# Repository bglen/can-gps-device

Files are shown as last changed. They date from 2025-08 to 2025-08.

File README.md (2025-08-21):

# can-gps-device

| Side | Top |
| --- | --- |
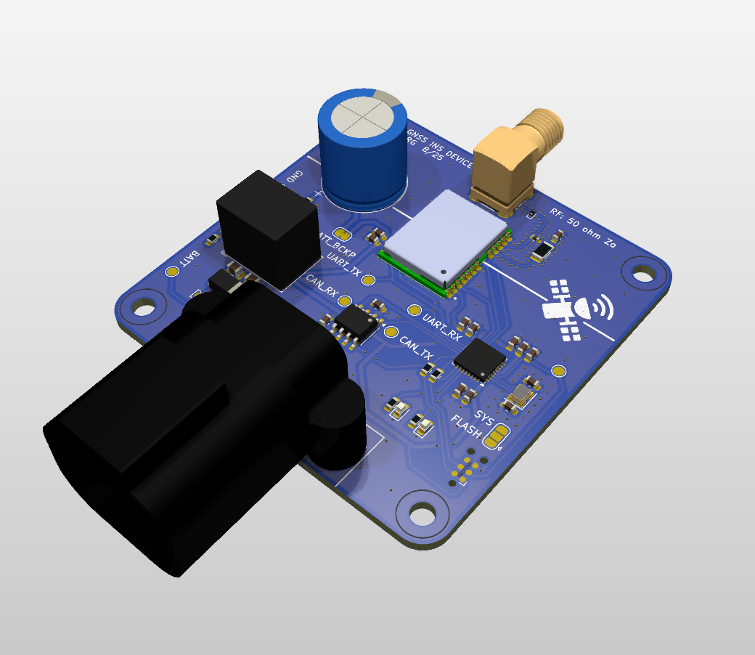
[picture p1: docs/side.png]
side
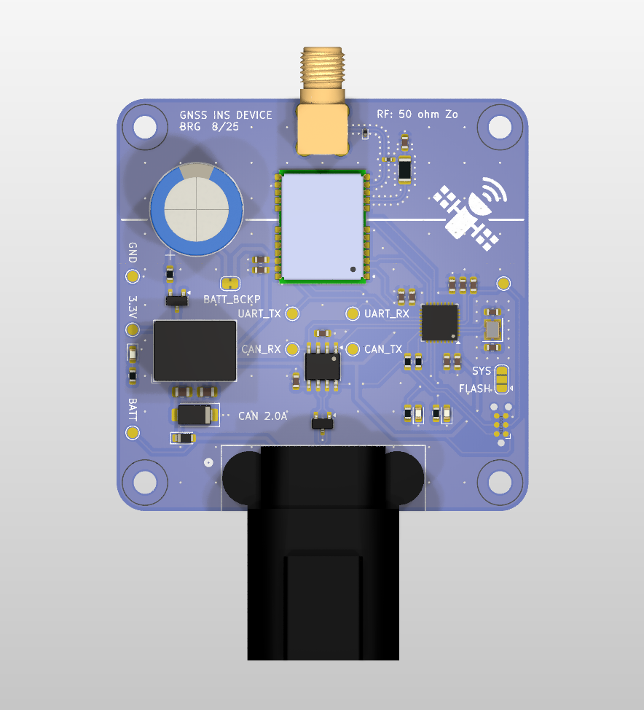
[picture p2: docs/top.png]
|  |  |

Simple, easy to use GPS module for CAN bus-networked vehicles.
- ublox NEO-M90V-20B GNSS + IMU dead reckoning module
- STM32F042
- CAN 2.0B
- Super capacitor circuit supports hot-start up to 30 minutes after first lock
- ublox ANN-MB5 antenna recomended

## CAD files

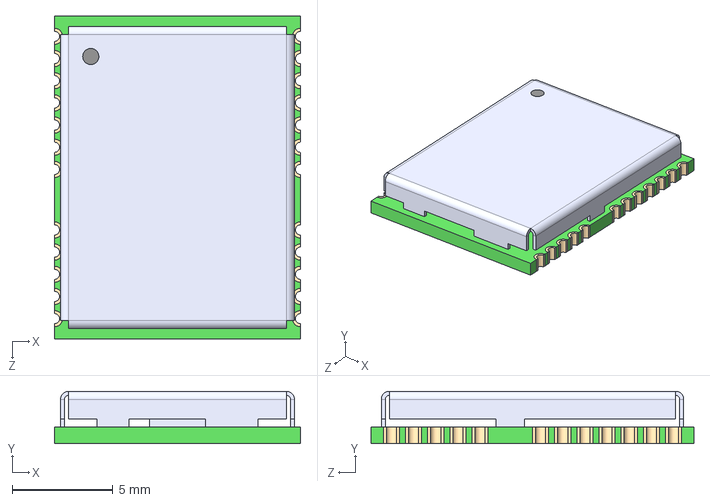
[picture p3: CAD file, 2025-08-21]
hardware/can_gps_device/3d_models/NEO-M9V-20B.step
12.2 x 2.60 x 16.0 mm

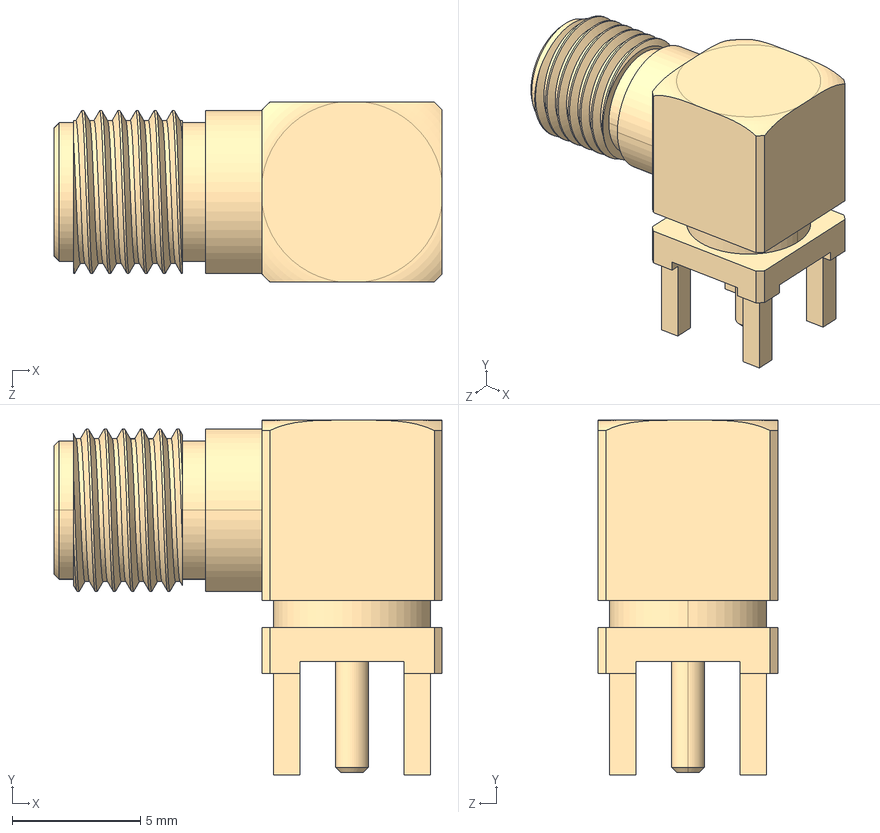
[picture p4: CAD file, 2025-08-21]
hardware/can_gps_device/3d_models/SMA-J-P-H-RA-TH1.STEP
15.1 x 13.8 x 7.00 mm

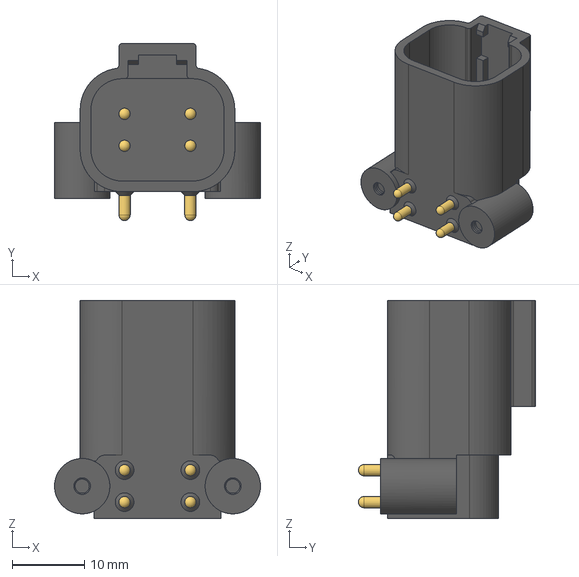
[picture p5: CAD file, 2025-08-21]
hardware/can_gps_device/3d_models/ATF13-4P-BM11.stp
28.5 x 24.5 x 30.2 mm

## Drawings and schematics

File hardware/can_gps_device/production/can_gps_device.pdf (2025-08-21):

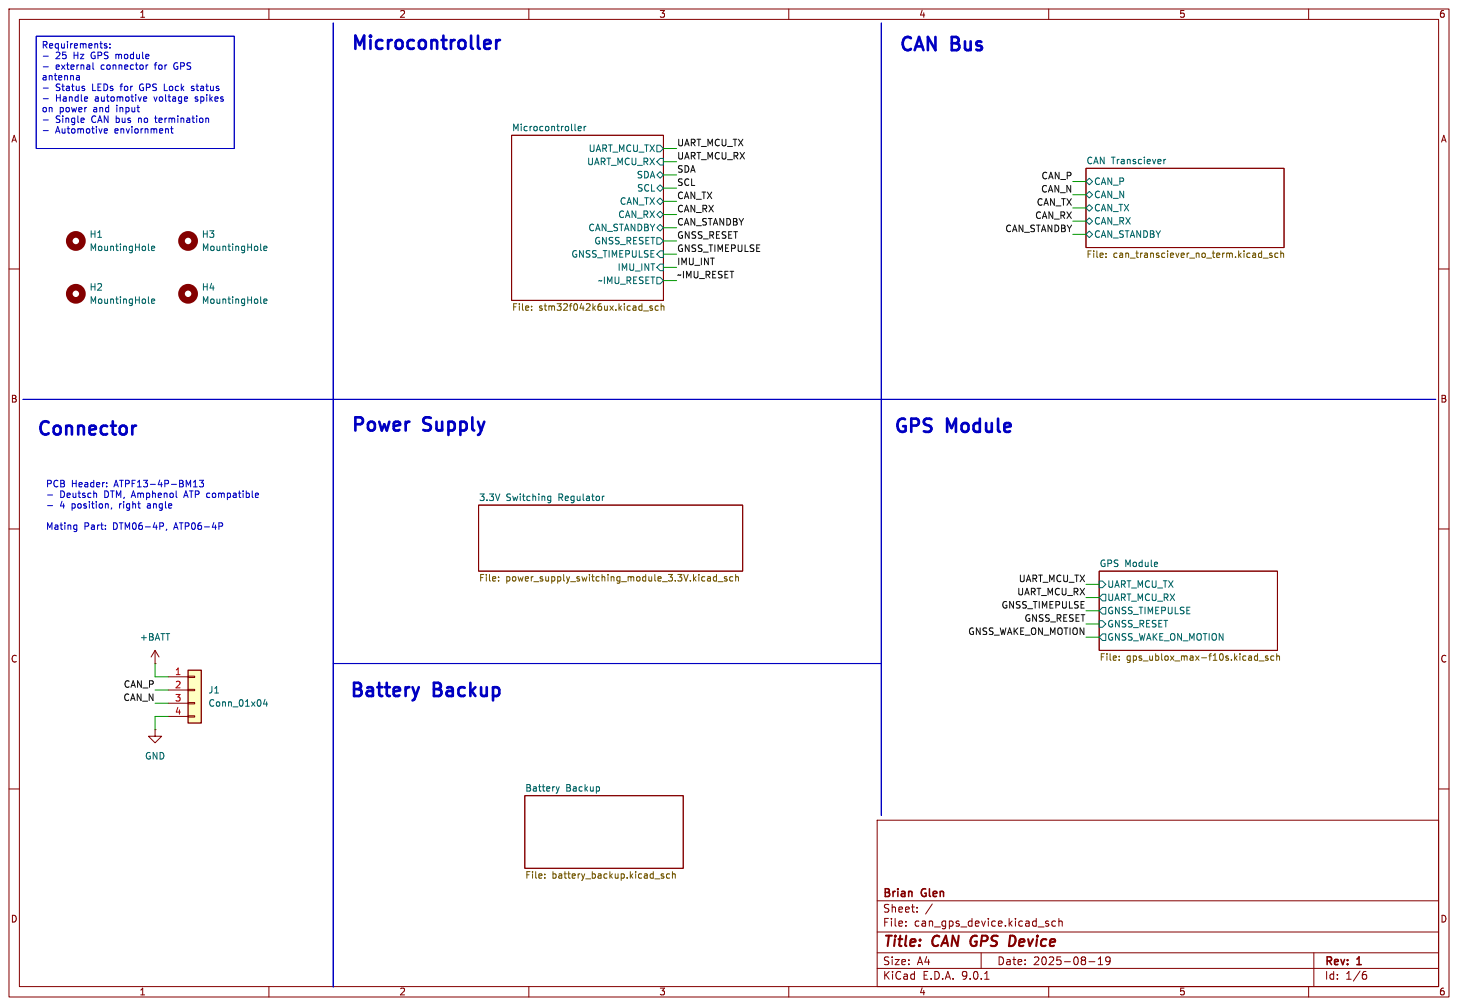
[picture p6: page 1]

IMU_INT SCL ~IMU_RESET Microcontroller File: stm32f042k6ux.kicad_sch Battery Backup File: battery_backup.kicad_sch

Requirements: - 25 Hz GPS module

antenna
- Status LEDs for GPS Lock status

PCB Header: ATPF13-4P-BM13
- Deutsch DTM, Amphenol ATP compatible

File: can_gps_device.kicad_sch Sheet: / Brian Glen

Id: 1/6 Title: CAN GPS Device

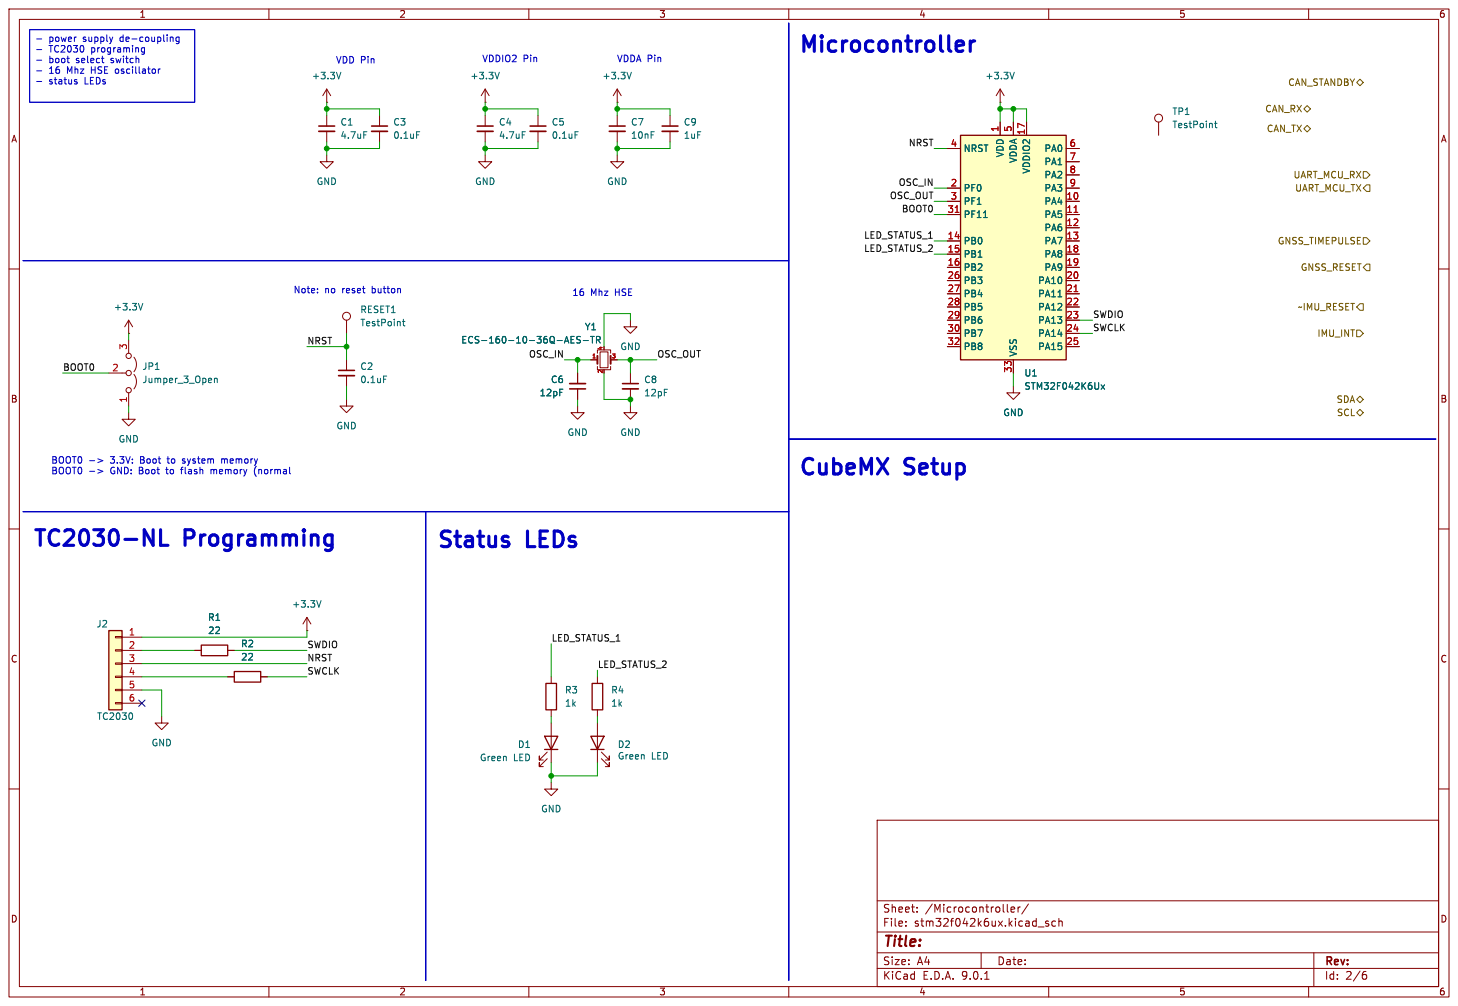
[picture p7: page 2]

- power supply de-coupling
- TC2030 programing
- boot select switch
- 16 Mhz HSE oscillator

Id: 2/6 Title: File: stm32f042k6ux.kicad_sch Sheet: /Microcontroller/

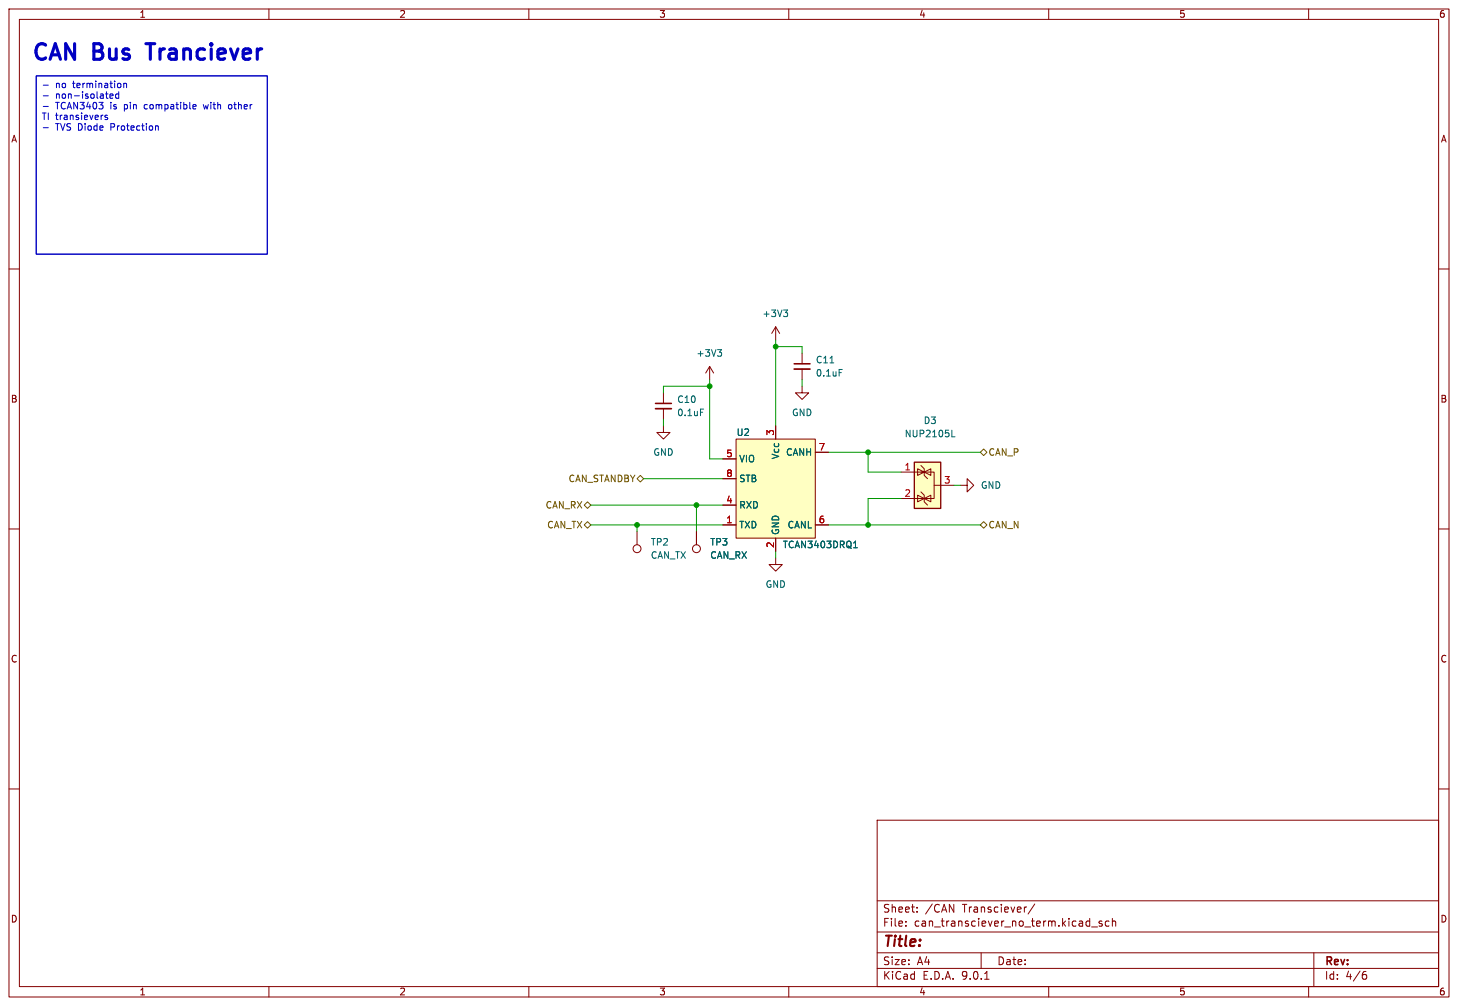
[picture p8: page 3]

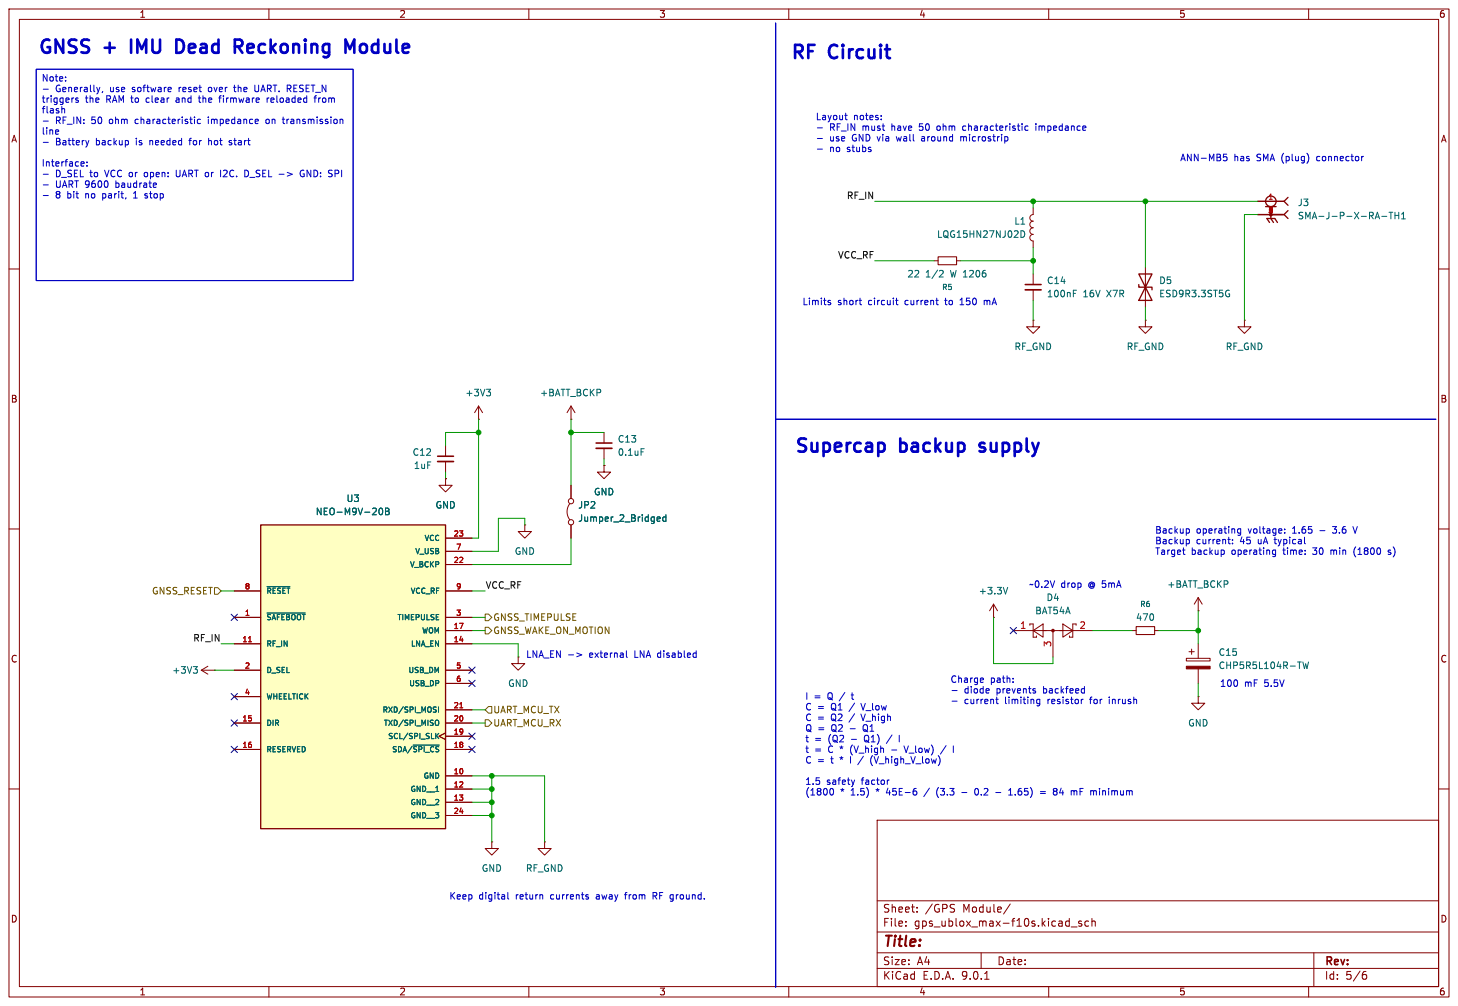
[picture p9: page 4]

flash
line
- Battery backup is needed for hot start

ANN-MB5 has SMA (plug) connector 100 mF 5.5V

- use GND via wall around microstrip

Charge path: - diode prevents backfeed

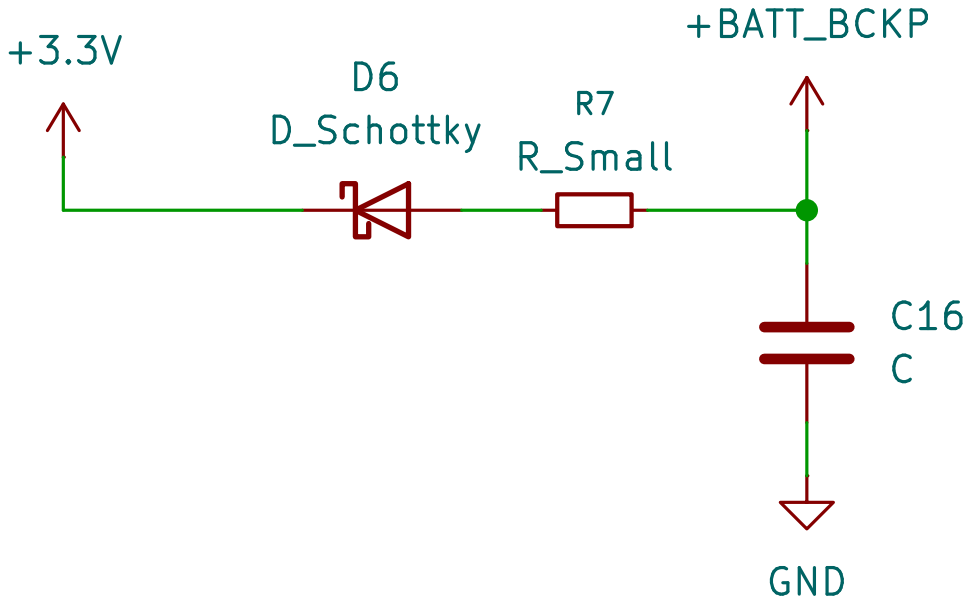
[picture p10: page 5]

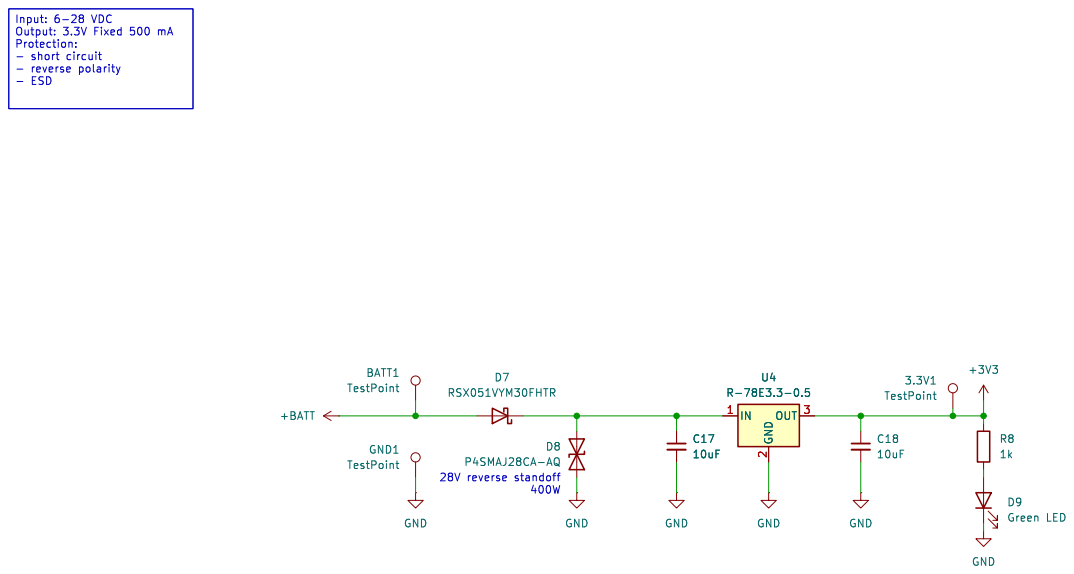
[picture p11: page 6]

Protection: - short circuit - reverse polarity

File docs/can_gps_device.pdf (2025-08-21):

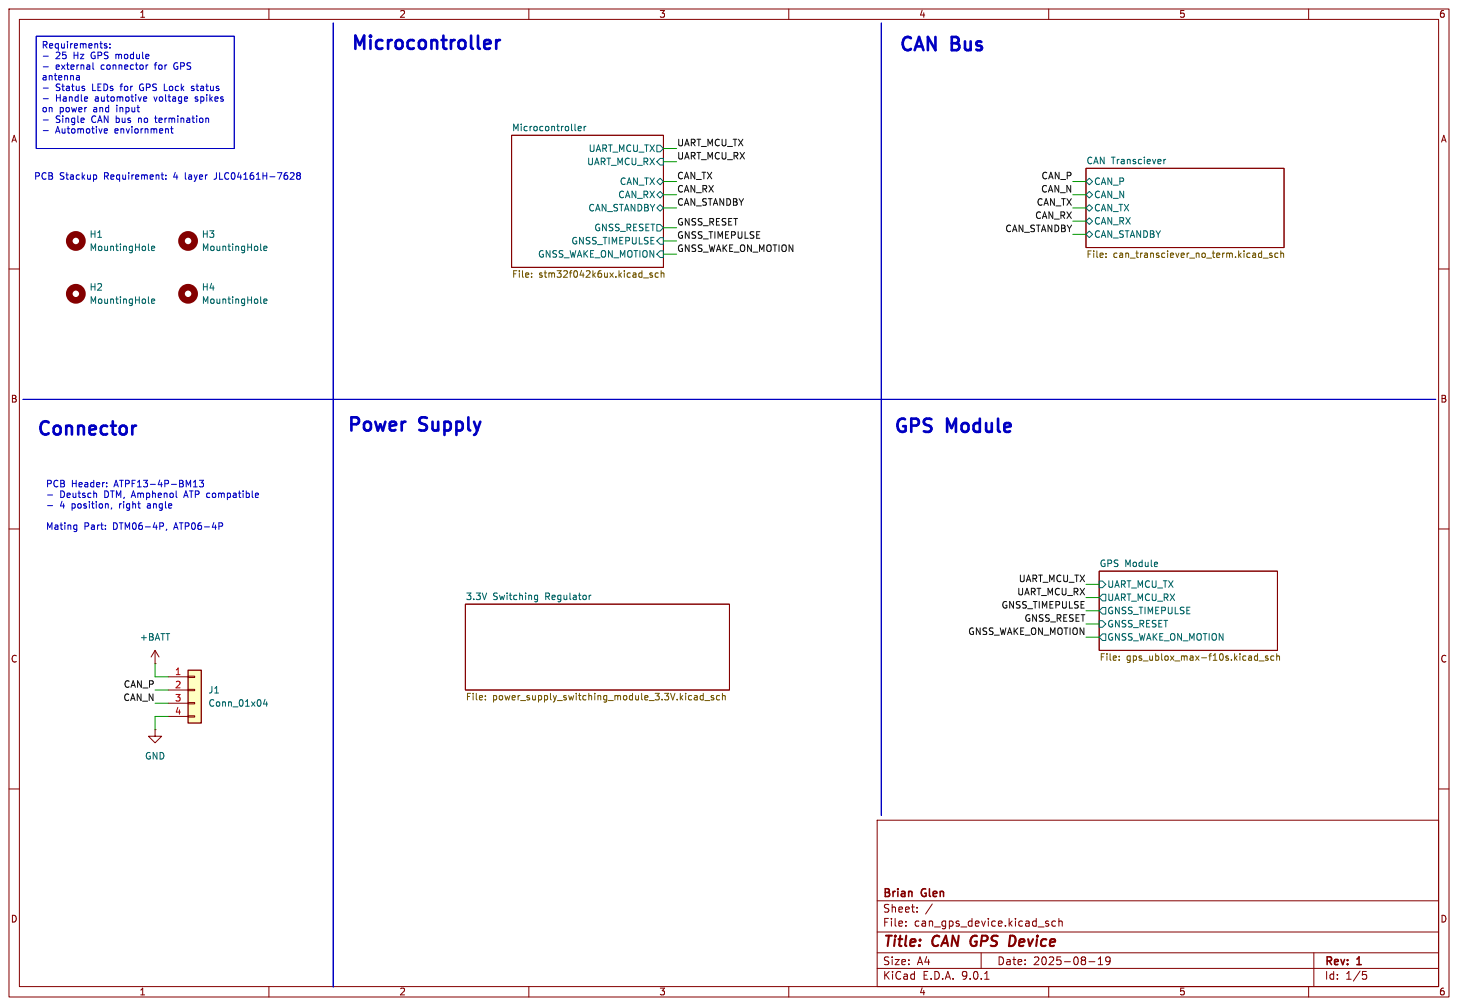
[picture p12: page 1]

Requirements: - 25 Hz GPS module

antenna
- Status LEDs for GPS Lock status

- Deutsch DTM, Amphenol ATP compatible

File: can_gps_device.kicad_sch Sheet: / Brian Glen

Id: 1/5 Title: CAN GPS Device

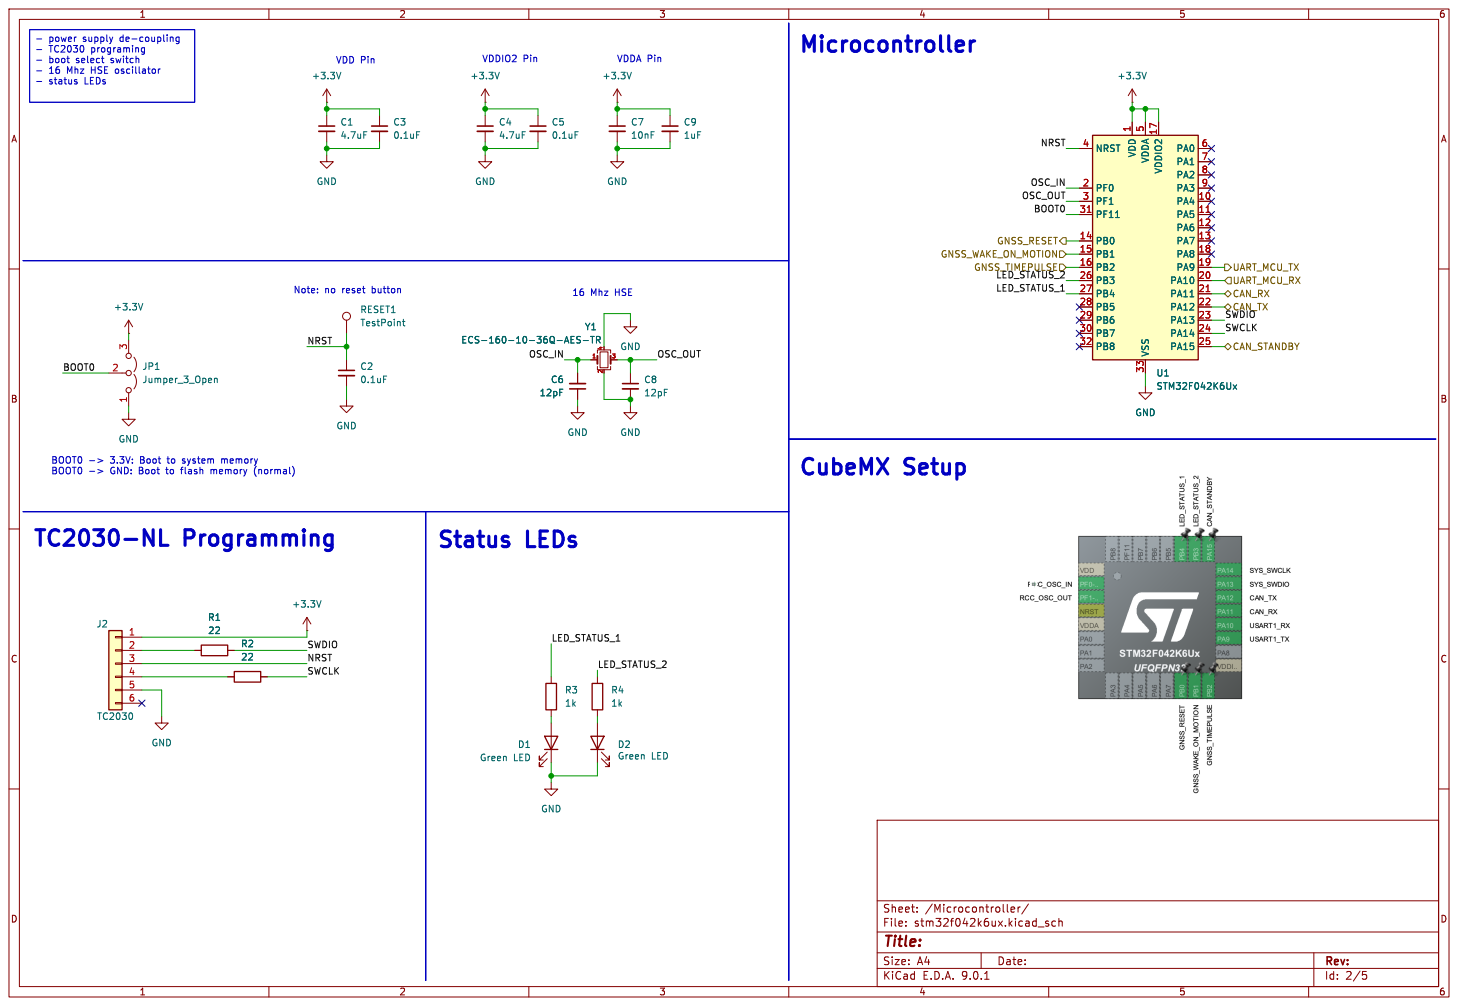
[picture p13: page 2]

- power supply de-coupling
- TC2030 programing
- boot select switch
- 16 Mhz HSE oscillator

Id: 2/5 Title: File: stm32f042k6ux.kicad_sch Sheet: /Microcontroller/

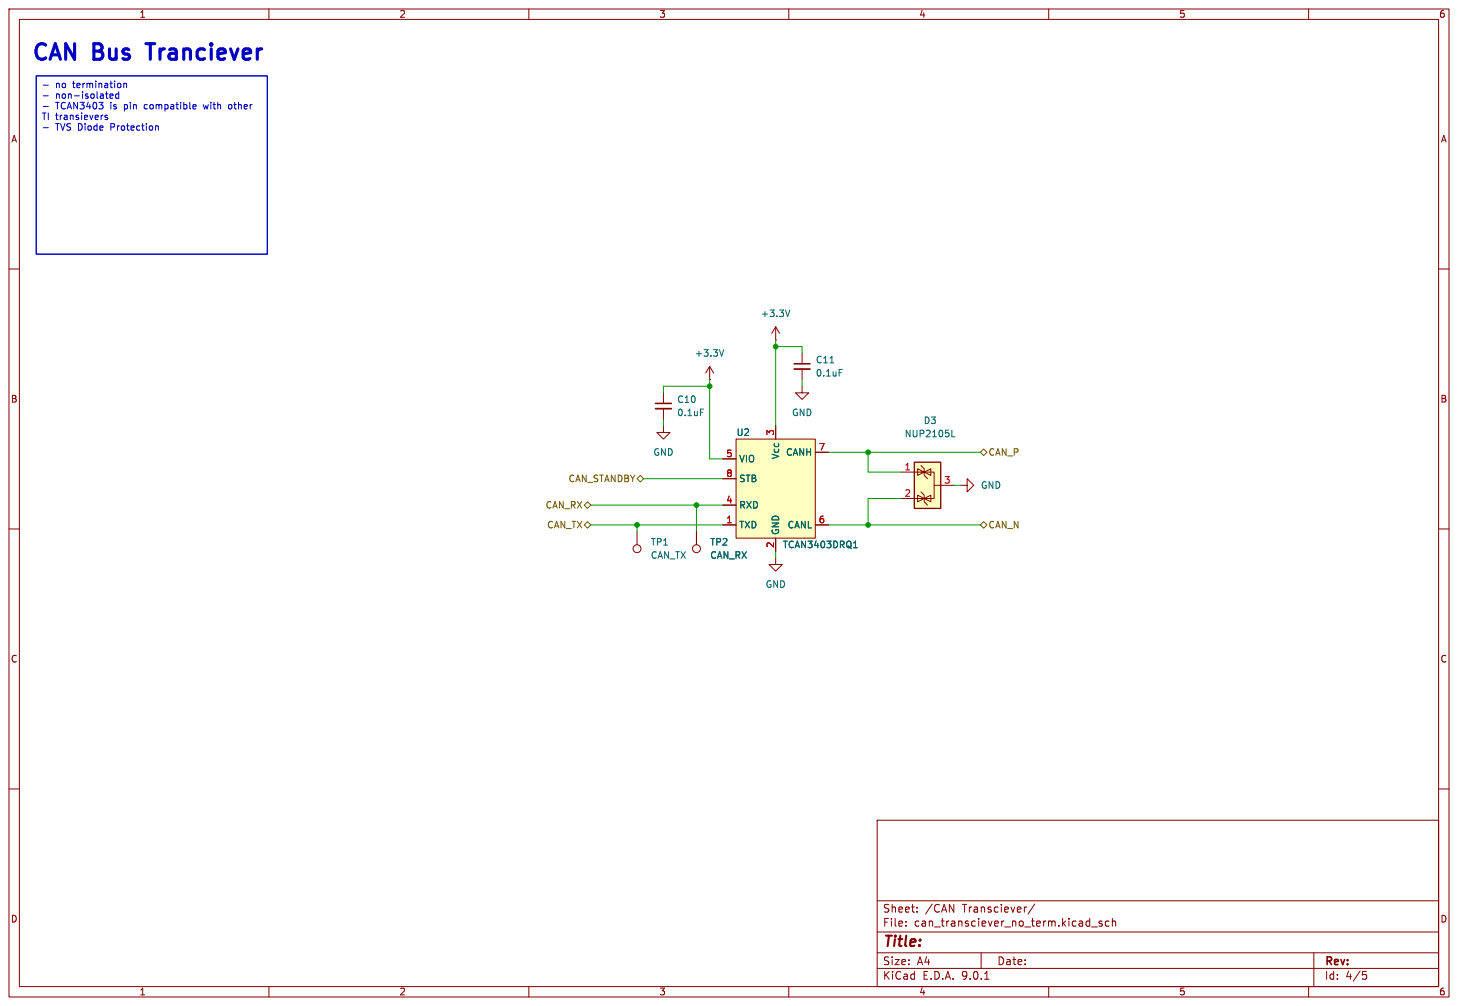
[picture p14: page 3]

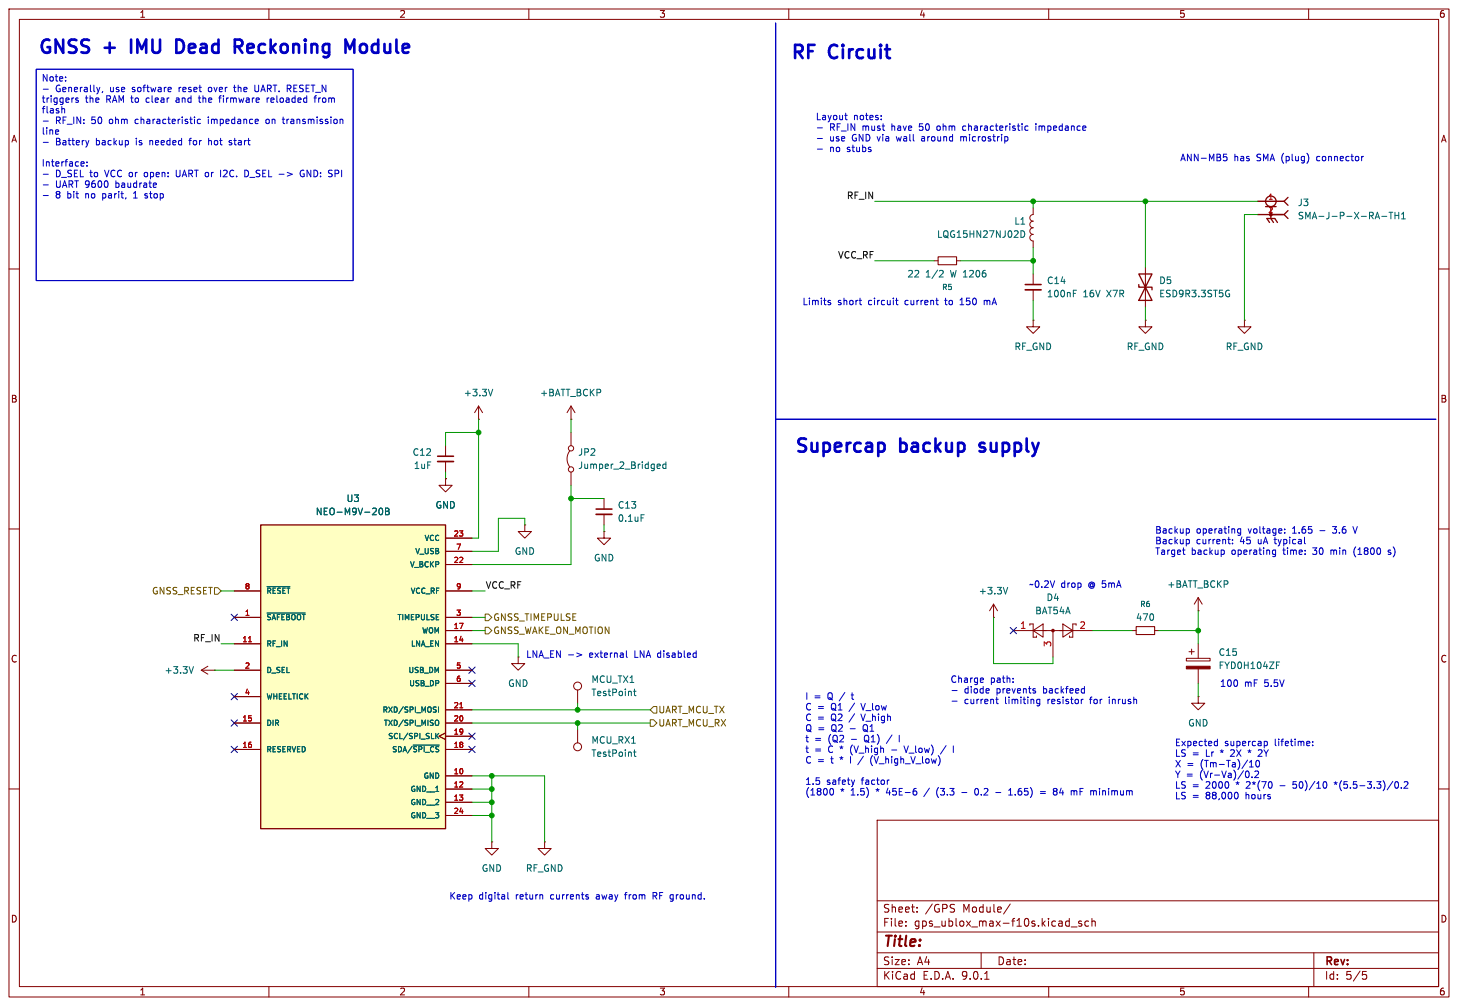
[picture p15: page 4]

flash
line
- Battery backup is needed for hot start

- use GND via wall around microstrip

Charge path: - diode prevents backfeed

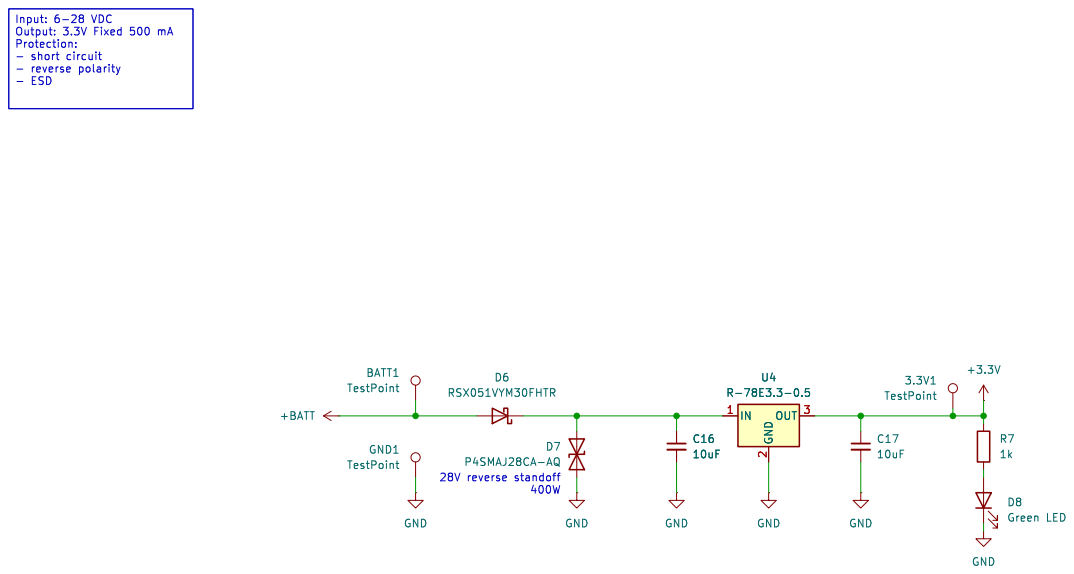
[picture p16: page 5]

Protection: - short circuit - reverse polarity

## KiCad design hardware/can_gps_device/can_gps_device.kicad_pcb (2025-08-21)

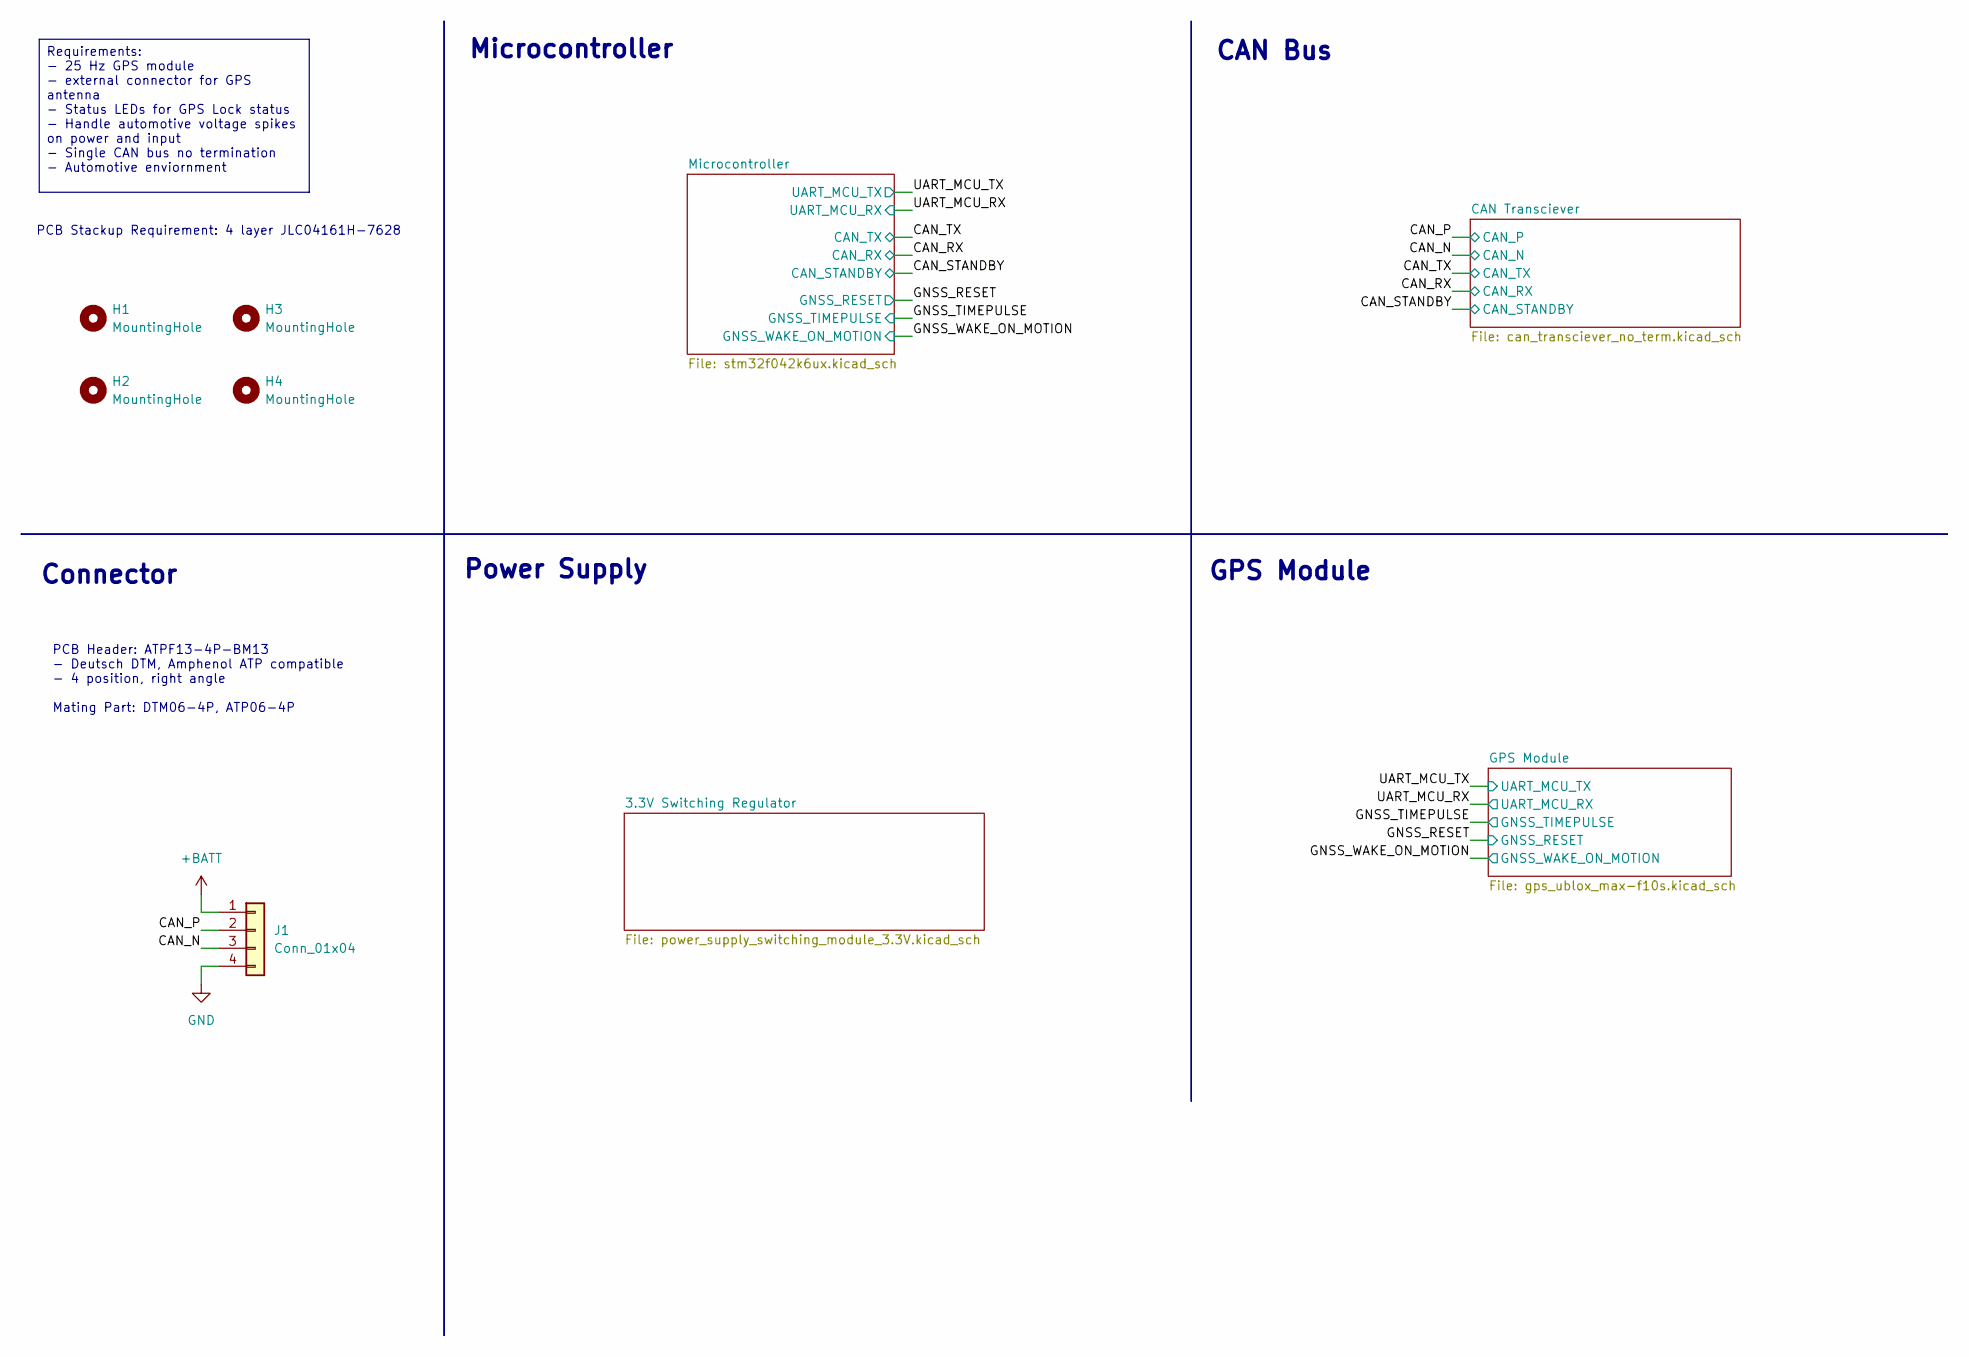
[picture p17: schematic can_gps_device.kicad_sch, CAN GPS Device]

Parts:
H1, H2, H3, H4: MountingHole; MountingHole_3.2mm_M3
J1: Conn_01x04; ATF13-4P-BM13_AMP

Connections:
+BATT: J1.1; also elsewhere on the board
/CAN_N: J1.3; also elsewhere on the board
/CAN_P: J1.2; also elsewhere on the board
GND: J1.4; also elsewhere on the board

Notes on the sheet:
Connector
GPS Module
PCB Header: ATPF13-4P-BM13 - Deutsch DTM, Amphenol ATP compatible - 4 position, right angle Mating Part: DTM06-4P, ATP06-4P
Power Supply
CAN Bus
PCB Stackup Requirement: 4 layer JLC04161H-7628
Microcontroller
Requirements: - 25 Hz GPS module - external connector for GPS antenna - Status LEDs for GPS Lock status - Handle automotive voltage spikes on power and input - Single CAN bus no termination - Automotive enviornment

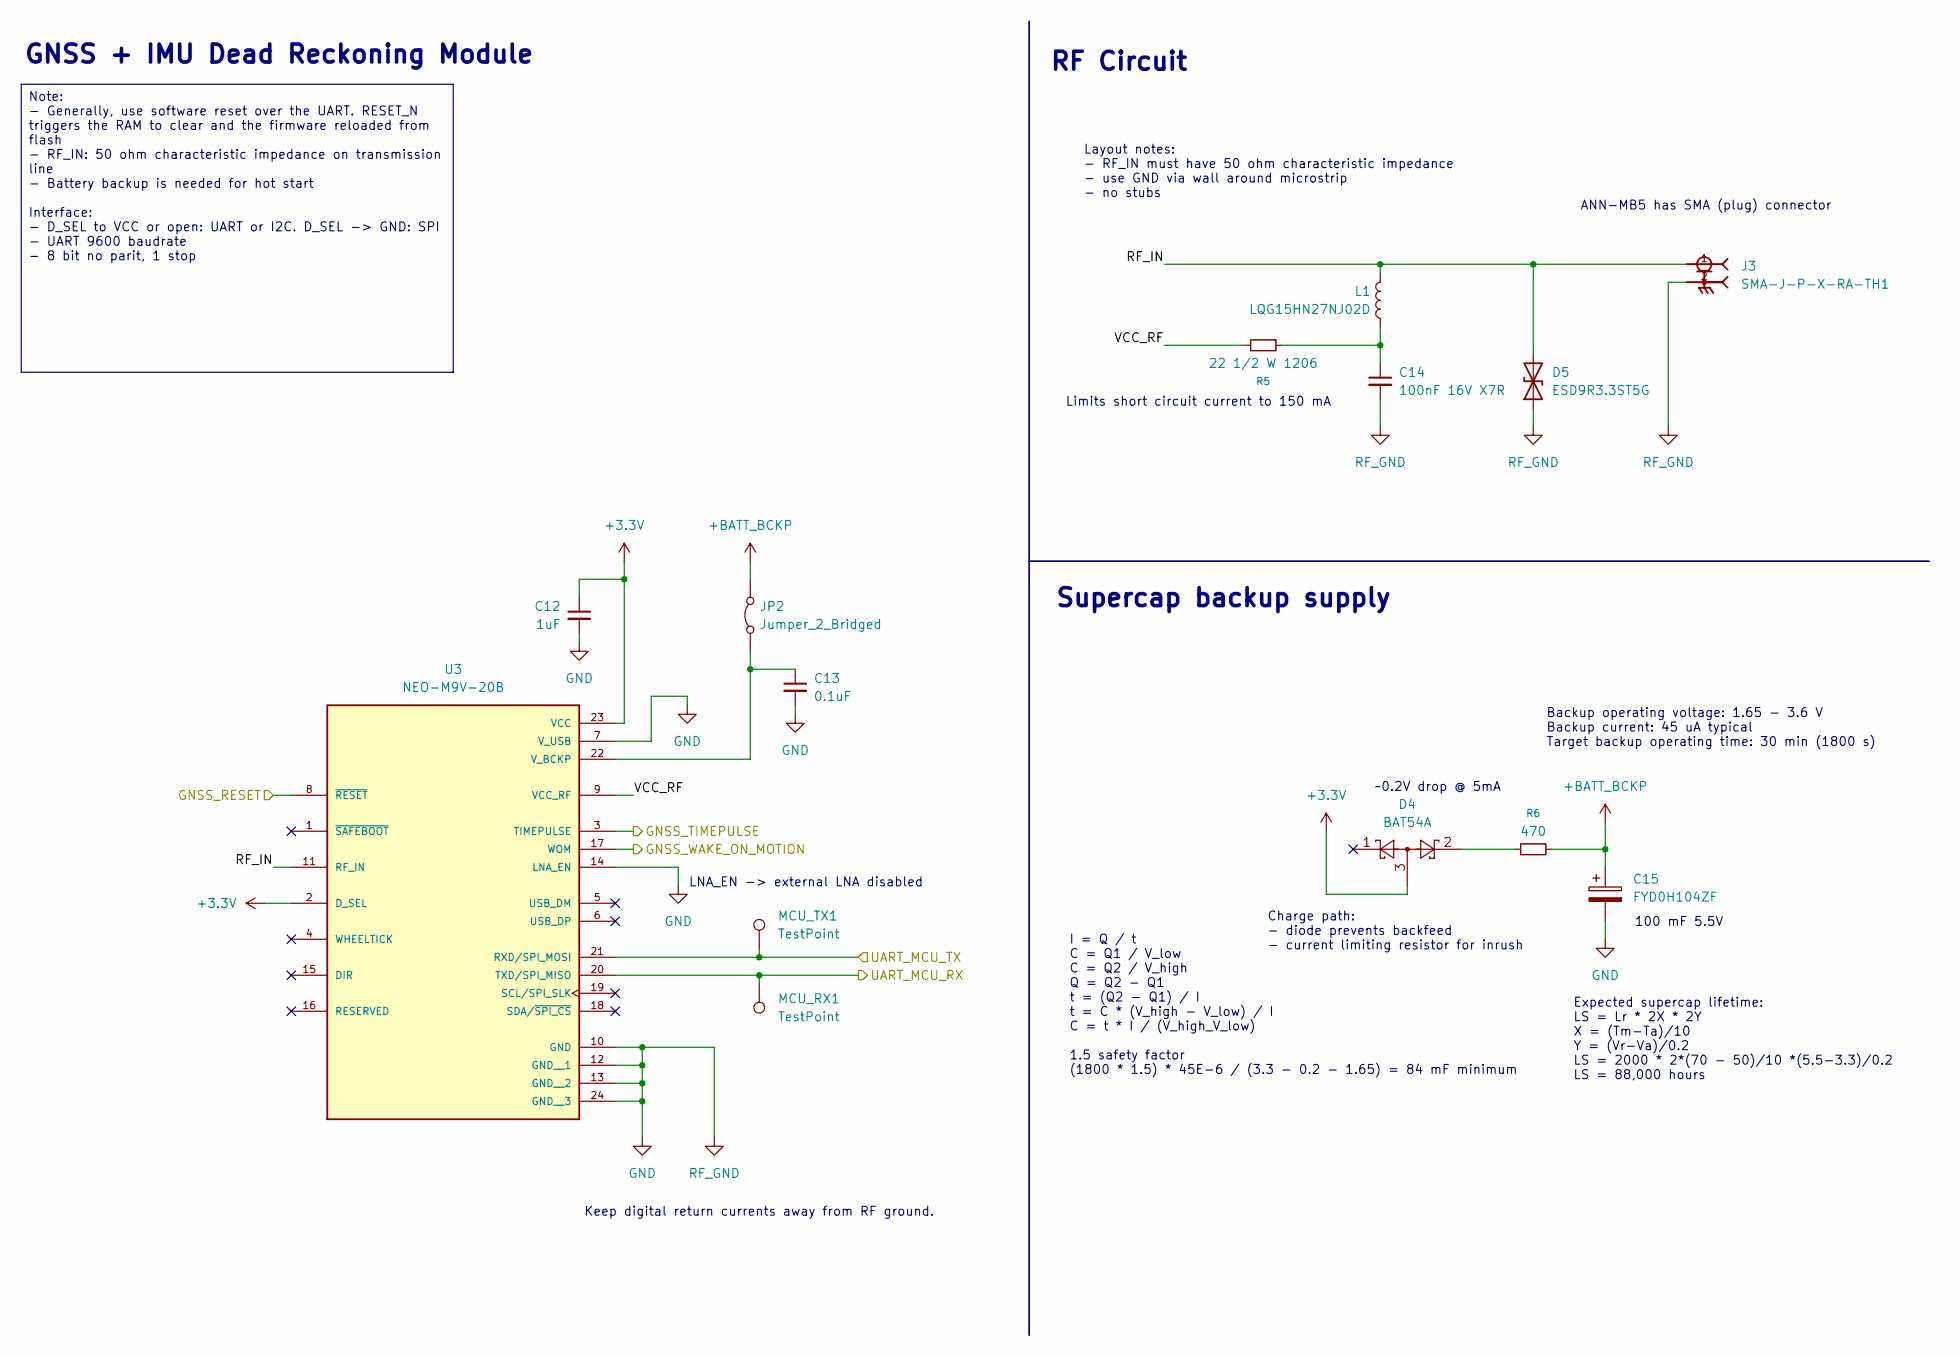
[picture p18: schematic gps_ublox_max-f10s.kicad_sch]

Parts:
C12: 1uF; C_0603_1608Metric
C13: 0.1uF; C_0603_1608Metric
C14: 100nF 16V X7R; C_0603_1608Metric
C15: FYD0H104ZF; CP_Radial_D13.0mm_P5.00mm
D4: BAT54A; SOT-23
D5: ESD9R3.3ST5G; D_SOD-923
J3: SMA-J-P-X-RA-TH1; SAMTEC_SMA-J-P-X-RA-TH1; PARTREV K
JP2: Jumper_2_Bridged; SolderJumper-2_P1.3mm_Bridged_RoundedPad1.0x1.5mm
L1: LQG15HN27NJ02D; L_0402_1005Metric_Pad0.77x0.64mm_HandSolder
MCU_RX1: TestPoint; TestPoint_Pad_D1.5mm
MCU_TX1: TestPoint; TestPoint_Pad_D1.5mm
R5: 22 1/2 W 1206; R_1206_3216Metric
R6: 470; R_0603_1608Metric
U3: NEO-M9V-20B; XCVR_NEO-M9V-20B; PARTREV C1

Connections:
+3.3V: C12.1, D4.3, U3.2 (D_SEL), U3.23 (VCC); also elsewhere on the board
+BATT_BCKP: C15.1, JP2.2 (B), R6.2
/GNSS_RESET: U3.8 (~RESET); also elsewhere on the board
/GNSS_TIMEPULSE: U3.3 (TIMEPULSE); also elsewhere on the board
/GNSS_WAKE_ON_MOTION: U3.17 (WOM); also elsewhere on the board
/GPS Module/RF_IN: D5.2 (A2), J3.1, L1.1, U3.11 (RF_IN)
/GPS Module/VCC_RF: R5.2, U3.9 (VCC_RF)
/UART_MCU_RX: MCU_RX1.1, U3.20 (TXD/SPI_MISO); also elsewhere on the board
/UART_MCU_TX: MCU_TX1.1, U3.21 (RXD/SPI_MOSI); also elsewhere on the board
GND: C12.2, C13.2, C14.2, C15.2, D5.1 (A1), J3.2, J3.3, J3.4, J3.5, U3.7 (V_USB), U3.10 (GND), U3.12 (GND__1), U3.13 (GND__2), U3.14 (LNA_EN), U3.24 (GND__3); also elsewhere on the board
unnamed: C14.1, L1.2, R5.1
unnamed: D4.2, R6.1
unnamed: C13.1, JP2.1 (A), U3.22 (V_BCKP)

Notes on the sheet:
Layout notes: - RF_IN must have 50 ohm characteristic impedance - use GND via wall around microstrip - no stubs
RF Circuit
Backup operating voltage: 1.65 - 3.6 V Backup current: 45 uA typical Target backup operating time: 30 min (1800 s)
Limits short circuit current to 150 mA
~0.2V drop @ 5mA
100 mF 5.5V
ANN-MB5 has SMA (plug) connector
LNA_EN -> external LNA disabled
I = Q / t C = Q1 / V_low C = Q2 / V_high Q = Q2 - Q1 t = (Q2 - Q1) / I t = C * (V_high - V_low) / I C = t * I / (V_high_V_low) 1.5 safety factor (1800 * 1.5) * 45E-6 / (3.3 - 0.2 - 1.65) = 84 mF minimum
Expected supercap lifetime: LS = Lr * 2X * 2Y X = (Tm-Ta)/10 Y = (Vr-Va)/0.2 LS = 2000 * 2*(70 - 50)/10 *(5.5-3.3)/0.2 LS = 88,000 hours
GNSS + IMU Dead Reckoning Module
Keep digital return currents away from RF ground.
Supercap backup supply
Charge path: - diode prevents backfeed - current limiting resistor for inrush
Note: - Generally, use software reset over the UART. RESET_N triggers the RAM to clear and the firmware reloaded from flash - RF_IN: 50 ohm characteristic impedance on transmission line - Battery backup is needed for hot start Interface: - D_SEL to VCC or open: UART or I2C. D_SEL -> GND: SPI - UART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

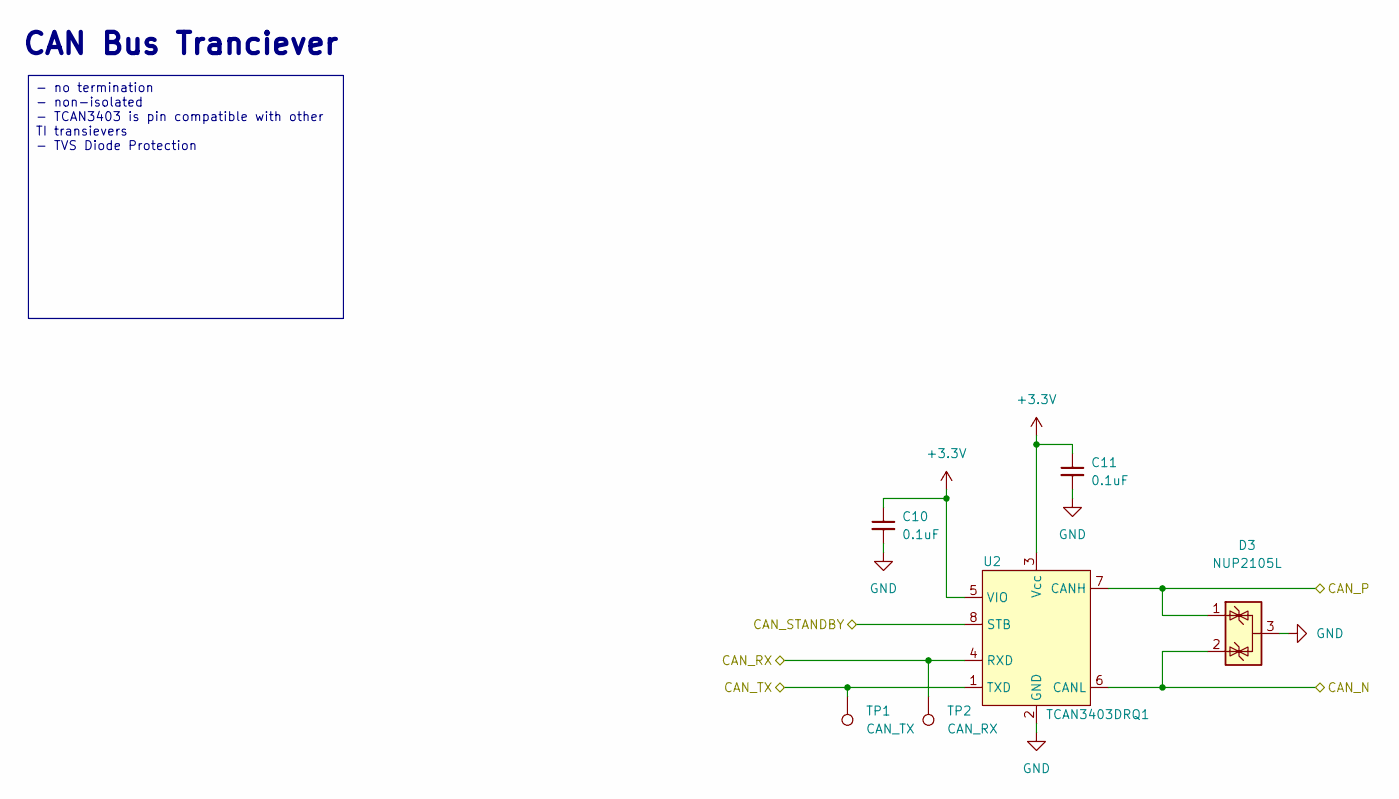
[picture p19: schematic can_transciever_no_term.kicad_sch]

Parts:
C10, C11: 0.1uF; C_0603_1608Metric
D3: NUP2105L; SOT-23
TP1: CAN_TX; TestPoint_Pad_D1.5mm
TP2: CAN_RX; TestPoint_Pad_D1.5mm
U2: TCAN3403DRQ1; SOIC-8_3.9x4.9mm_P1.27mm

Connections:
+3.3V: C10.1, C11.1, U2.3 (Vcc), U2.5 (VIO); also elsewhere on the board
/CAN_N: D3.2 (K), U2.6 (CANL); also elsewhere on the board
/CAN_P: D3.1 (K), U2.7 (CANH); also elsewhere on the board
/CAN_RX: TP2.1, U2.4 (RXD); also elsewhere on the board
/CAN_STANDBY: U2.8 (STB); also elsewhere on the board
/CAN_TX: TP1.1, U2.1 (TXD); also elsewhere on the board
GND: C10.2, C11.2, D3.3 (A), U2.2 (GND); also elsewhere on the board

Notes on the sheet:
CAN Bus Tranciever
- no termination - non-isolated - TCAN3403 is pin compatible with other TI transievers - TVS Diode Protection

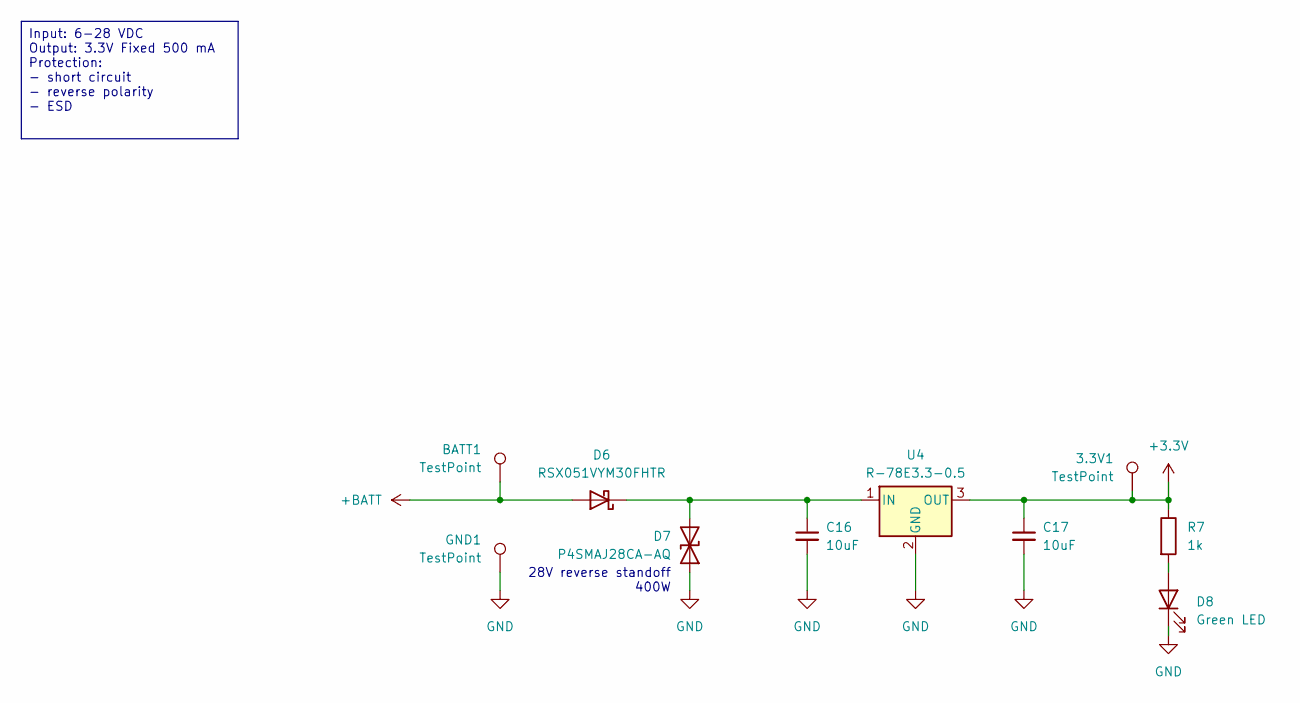
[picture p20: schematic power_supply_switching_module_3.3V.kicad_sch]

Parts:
3.3V1: TestPoint; TestPoint_Pad_D1.5mm
BATT1: TestPoint; TestPoint_Pad_D1.5mm
C16, C17: 10uF; C_0805_2012Metric
D6: RSX051VYM30FHTR; D_TUMD2
D7: P4SMAJ28CA-AQ; D_SMA
D8: Green LED; LED_0603_1608Metric
GND1: TestPoint; TestPoint_Pad_D1.5mm
R7: 1k; R_0603_1608Metric
U4: R-78E3.3-0.5; Converter_DCDC_RECOM_R-78E-0.5_THT

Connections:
+3.3V: 3.3V1.1, C17.1, R7.1, U4.3 (OUT); also elsewhere on the board
+BATT: BATT1.1, D6.2 (A); also elsewhere on the board
GND: C16.2, C17.2, D7.1 (A1), D8.1 (K), GND1.1, U4.2 (GND); also elsewhere on the board
unnamed: C16.1, D6.1 (K), D7.2 (A2), U4.1 (IN)
unnamed: D8.2 (A), R7.2

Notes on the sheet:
28V reverse standoff 400W
Input: 6-28 VDC Output: 3.3V Fixed 500 mA Protection: - short circuit - reverse polarity - ESD

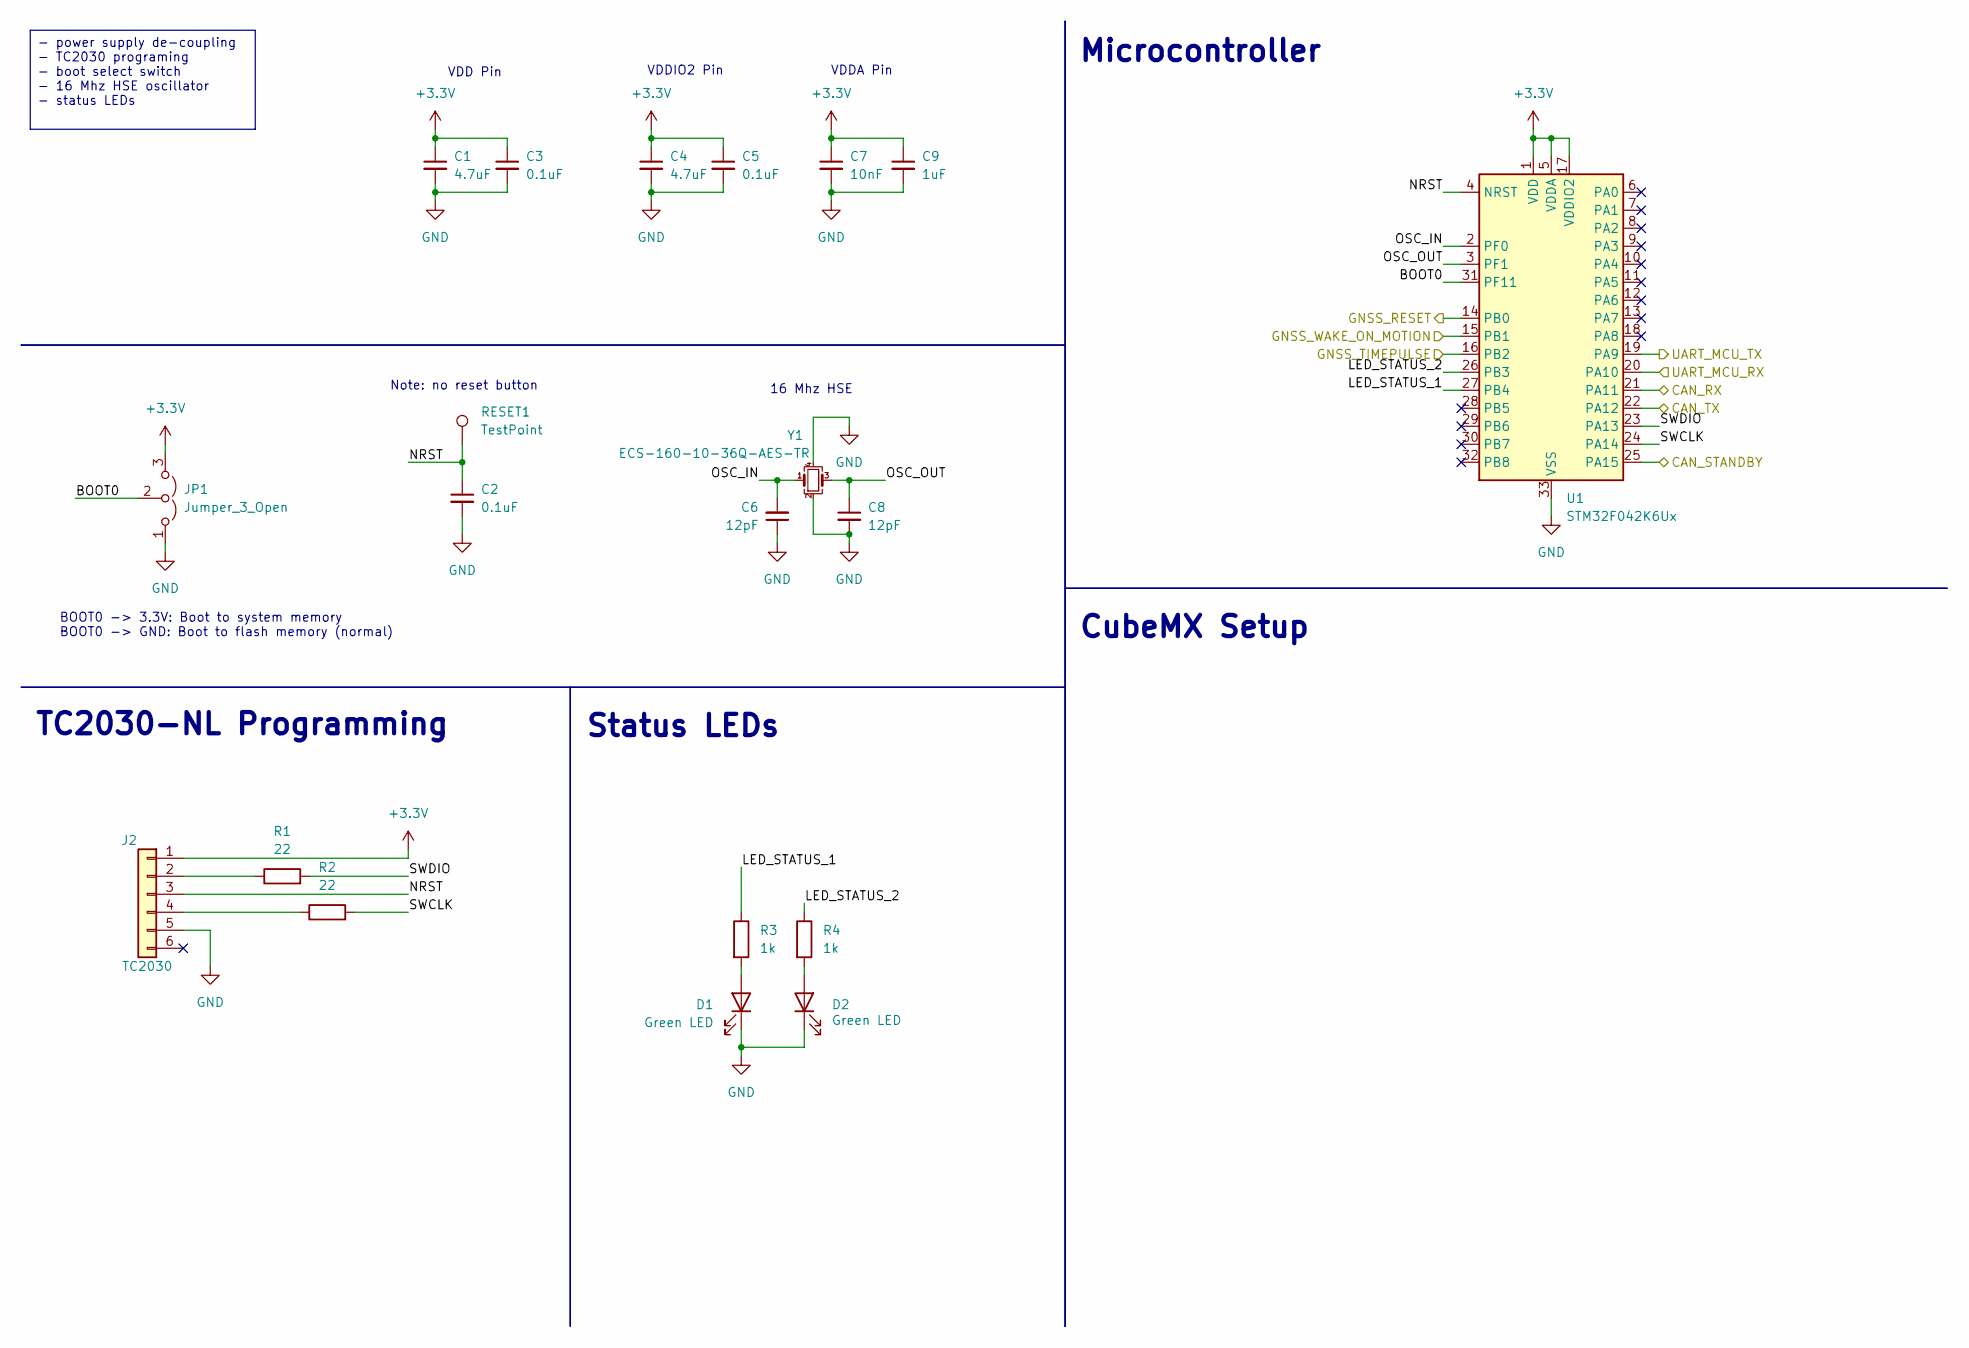
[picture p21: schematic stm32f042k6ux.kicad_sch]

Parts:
C1, C4: 4.7uF; C_0603_1608Metric
C2, C3, C5: 0.1uF; C_0603_1608Metric
C6, C8: 12pF; C_0603_1608Metric
C7: 10nF; C_0603_1608Metric
C9: 1uF; C_0603_1608Metric
D1, D2: Green LED; LED_0603_1608Metric
J2: TC2030; Tag-Connect_TC2030-IDC-NL_2x03_P1.27mm_Vertical
JP1: Jumper_3_Open; SolderJumper-3_P1.3mm_Open_RoundedPad1.0x1.5mm
R1, R2: 22; R_0603_1608Metric
R3, R4: 1k; R_0603_1608Metric
RESET1: TestPoint; TestPoint_Pad_D1.5mm
U1: STM32F042K6Ux; QFN-32-1EP_5x5mm_P0.5mm_EP3.45x3.45mm
Y1: ECS-160-10-36Q-AES-TR; Crystal_SMD_2520-4Pin_2.5x2.0mm

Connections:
+3.3V: C1.1, C3.1, C4.1, C5.1, C7.1, C9.1, J2.1, JP1.3 (B), U1.1 (VDD), U1.5 (VDDA), U1.17 (VDDIO2); also elsewhere on the board
/CAN_RX: U1.21 (PA11); also elsewhere on the board
/CAN_STANDBY: U1.25 (PA15); also elsewhere on the board
/CAN_TX: U1.22 (PA12); also elsewhere on the board
/GNSS_RESET: U1.14 (PB0); also elsewhere on the board
/GNSS_TIMEPULSE: U1.16 (PB2); also elsewhere on the board
/GNSS_WAKE_ON_MOTION: U1.15 (PB1); also elsewhere on the board
/Microcontroller/BOOT0: JP1.2 (C), U1.31 (PF11)
/Microcontroller/LED_STATUS_1: R3.1, U1.27 (PB4)
/Microcontroller/LED_STATUS_2: R4.1, U1.26 (PB3)
/Microcontroller/NRST: C2.1, J2.3, RESET1.1, U1.4 (NRST)
/Microcontroller/OSC_IN: C6.2, U1.2 (PF0), Y1.1
/Microcontroller/OSC_OUT: C8.1, U1.3 (PF1), Y1.3
/Microcontroller/SWCLK: R2.2, U1.24 (PA14)
/Microcontroller/SWDIO: R1.2, U1.23 (PA13)
/UART_MCU_RX: U1.20 (PA10); also elsewhere on the board
/UART_MCU_TX: U1.19 (PA9); also elsewhere on the board
GND: C1.2, C2.2, C3.2, C4.2, C5.2, C6.1, C7.2, C8.2, C9.2, D1.1 (K), D2.1 (K), J2.5, JP1.1 (A), U1.33 (VSS), Y1.2, Y1.4; also elsewhere on the board
unnamed: D1.2 (A), R3.2
unnamed: D2.2 (A), R4.2
unnamed: J2.2, R1.1
unnamed: J2.4, R2.1

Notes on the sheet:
Microcontroller
VDD Pin
TC2030-NL Programming
Note: no reset button
16 Mhz HSE
CubeMX Setup
VDDA Pin
BOOT0 -> 3.3V: Boot to system memory BOOT0 -> GND: Boot to flash memory (normal)
Status LEDs
VDDIO2 Pin
- power supply de-coupling - TC2030 programing - boot select switch - 16 Mhz HSE oscillator - status LEDs

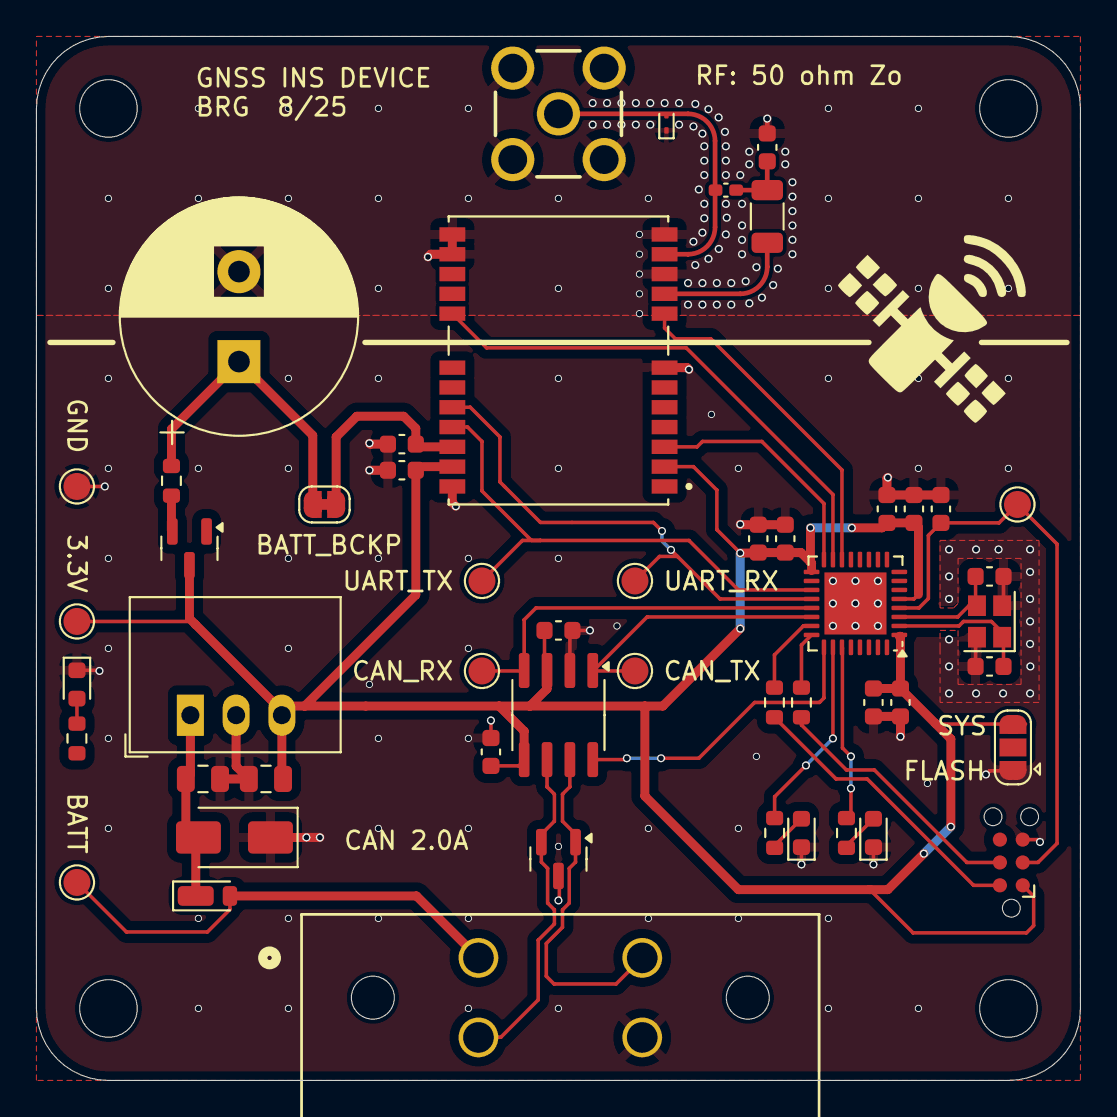
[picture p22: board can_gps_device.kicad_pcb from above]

Board: 4 copper layers, 58.0 x 58.0 mm, 55 parts (0 on the bottom side), 33 nets.

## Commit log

2025-08-21 Schematic Initial Rev
    [ATF13-4P-BM11.stp, NEO-M9V-20B.step, SMA-J-P-H-RA-TH1.STEP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]
2025-08-21 PCB design rev 1
    [can_gps_device.kicad_pcb, can_transciever_no_term.kicad_sch, gps_ublox_max-f10s.kicad_sch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]
2025-08-21 Updated MX config and schematic PDF
    [can_gps_device.kicad_pcb, can_gps_device.kicad_sch, stm32f042k6ux.kicad_sch]

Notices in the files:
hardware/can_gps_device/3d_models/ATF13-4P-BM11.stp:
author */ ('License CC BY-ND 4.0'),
